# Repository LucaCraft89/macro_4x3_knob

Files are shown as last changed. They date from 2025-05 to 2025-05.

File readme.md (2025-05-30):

# macro_4x3_knob

macro_4x3_knob
Image Coming soon

* Keyboard Creators: 
- [Luca Dall'Acqua](https://github.com/lucacraft89) PCB and FW
- [Simone Folino](https://github.com/Simone02472) 3D Modeling
* Hardware Supported: Arduino Pro Micro, Custom PCB
* Hardware Availability: AliExpress or any mayor online store
* Status: New improved PCB revision and subsequent 3d Model revision in development

Make example for this keyboard (after setting up your build environment):
```bash
make macro_4x3_knob:default
```
Flashing example for this keyboard:
```bash
make macro_4x3_knob:default:flash
```
See the [build environment setup](https://docs.qmk.fm/#/getting_started_build_tools) and the [make instructions](https://docs.qmk.fm/#/getting_started_make_guide) for more information. Brand new to QMK? Start with our [Complete Newbs Guide](https://docs.qmk.fm/#/newbs).

## 3D models 
| Part  | File |
| :--- | :----: |
| TOP | [V1.0](https://github.com/LucaCraft89/macro_4x3_knob/3D/V1/top1.0.STL) | 
| BOTTOM | [V1.0](https://github.com/LucaCraft89/macro_4x3_knob/3D/V1/bottom1.0.STL) | 

## Gerber files

[V1](https://github.com/LucaCraft89/macro_4x3_knob/PCB/Gerber/V1/V1.zip)
- NOTE: PCB has space for oled display that was never implemented, ignore it

## VIAL
VIAL is supported just flash the layout
```bash
make macro_4x3_knob:vial:flash
```

## Bootloader
Enter the bootloader in 3 ways:

* **Bootmagic reset**: Hold down the key at (0,0) in the matrix (usually the top left key or Escape) and plug in the keyboard
* **Physical reset button**: Briefly press the button on the back of the PCB - some may have pads you must short instead
* **Keycode in layout**: Press the key mapped to `QK_BOOT` if it is available

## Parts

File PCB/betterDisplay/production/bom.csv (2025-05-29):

Designator | Footprint | Quantity | Value | LCSC Part #
D1, D10, D11, D12, D2, D3, D4, D5, D6, D7, D8, D9 | Diode_DO-35 | 12 | Diode
J1 | OLED_128x32 | 1 | OLED_128x32
S1, S10, S11, S12, S2, S3, S4, S5, S6, S7, S8, S9 | MX_PCB_1.00u | 12 | Keyswitch
SW1 | Encoder_EC11_MX | 1 | RotaryEncoder_Switch_MP
U1 | Arduino_Pro_Micro | 1 | Arduino_Pro_Micro

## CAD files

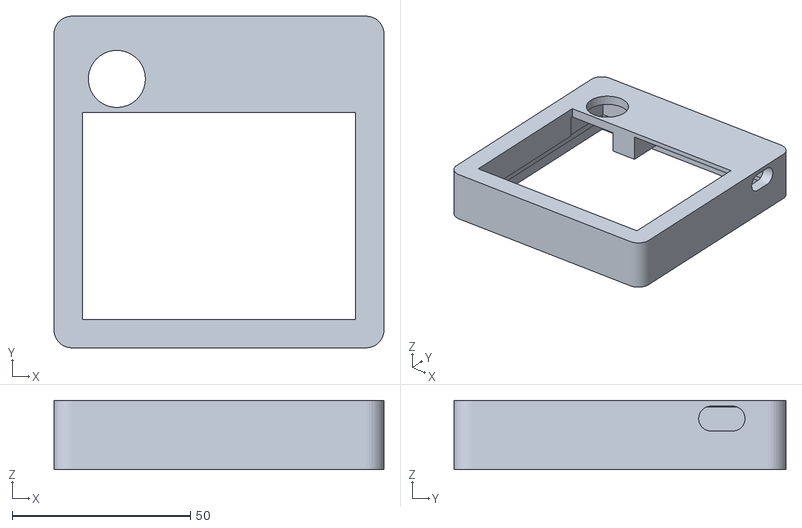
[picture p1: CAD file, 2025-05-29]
3D/V1/top1.0.STL
92.5 x 93.0 x 19.4

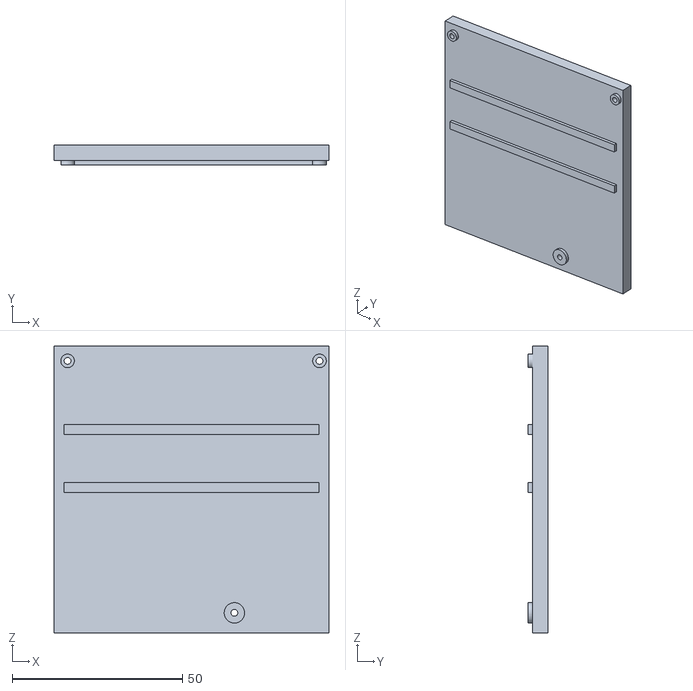
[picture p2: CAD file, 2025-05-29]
3D/V1/bottom1.0.STL
80.8 x 5.76 x 84.2

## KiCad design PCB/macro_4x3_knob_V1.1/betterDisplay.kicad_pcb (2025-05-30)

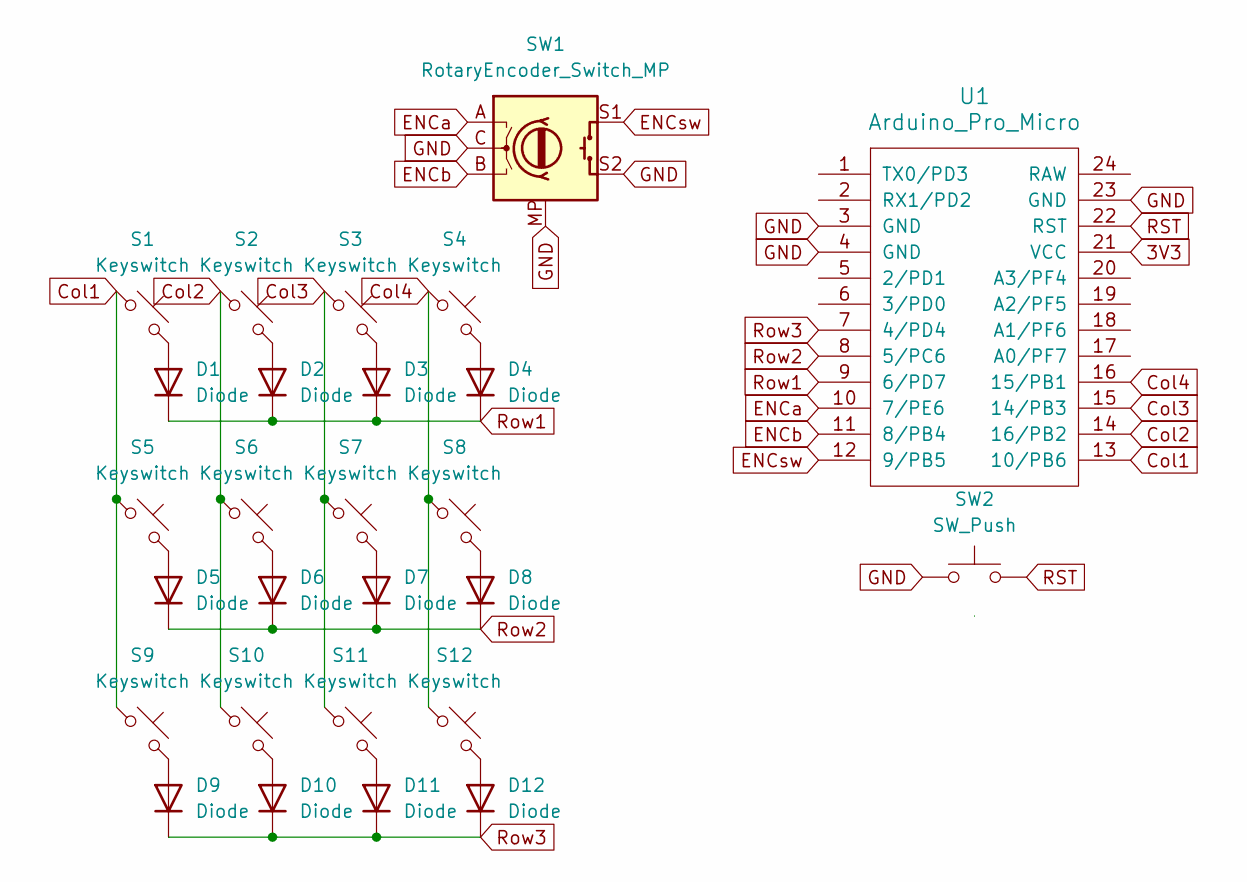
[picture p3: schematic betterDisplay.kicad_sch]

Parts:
D1, D2, D3, D4, D5, D6, D7, D8, D9, D10, D11, D12: Diode; Diode_DO-35
S1, S2, S3, S4, S5, S6, S7, S8, S9, S10, S11, S12: Keyswitch; MX_PCB_1.00u
SW1: RotaryEncoder_Switch_MP; Encoder_EC11_MX
SW2: SW_Push; SW_PUSH_6mm
U1: Arduino_Pro_Micro

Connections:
3V3: U1.21 (VCC)
Col1: S1.1, S5.1, S9.1, U1.13 (10/PB6)
Col2: S2.1, S6.1, S10.1, U1.14 (16/PB2)
Col3: S3.1, S7.1, S11.1, U1.15 (14/PB3)
Col4: S4.1, S8.1, S12.1, U1.16 (15/PB1)
ENCa: SW1.A, U1.10 (7/PE6)
ENCb: SW1.B, U1.11 (8/PB4)
ENCsw: SW1.S1, U1.12 (9/PB5)
GND: SW1.C, SW1.MP, SW1.S2, SW2.1, U1.3 (GND), U1.4 (GND), U1.23 (GND); also elsewhere on the board
unnamed: D1.2 (A), S1.2
unnamed: D2.2 (A), S2.2
unnamed: D3.2 (A), S3.2
unnamed: D4.2 (A), S4.2
unnamed: D5.2 (A), S5.2
unnamed: D6.2 (A), S6.2
unnamed: D7.2 (A), S7.2
unnamed: D8.2 (A), S8.2
unnamed: D9.2 (A), S9.2
unnamed: D10.2 (A), S10.2
unnamed: D11.2 (A), S11.2
unnamed: D12.2 (A), S12.2
RST: SW2.2, U1.22 (RST)
Row1: D1.1 (K), D2.1 (K), D3.1 (K), D4.1 (K), U1.9 (6/PD7)
Row2: D5.1 (K), D6.1 (K), D7.1 (K), D8.1 (K), U1.8 (5/PC6)
Row3: D9.1 (K), D10.1 (K), D11.1 (K), D12.1 (K), U1.7 (4/PD4)

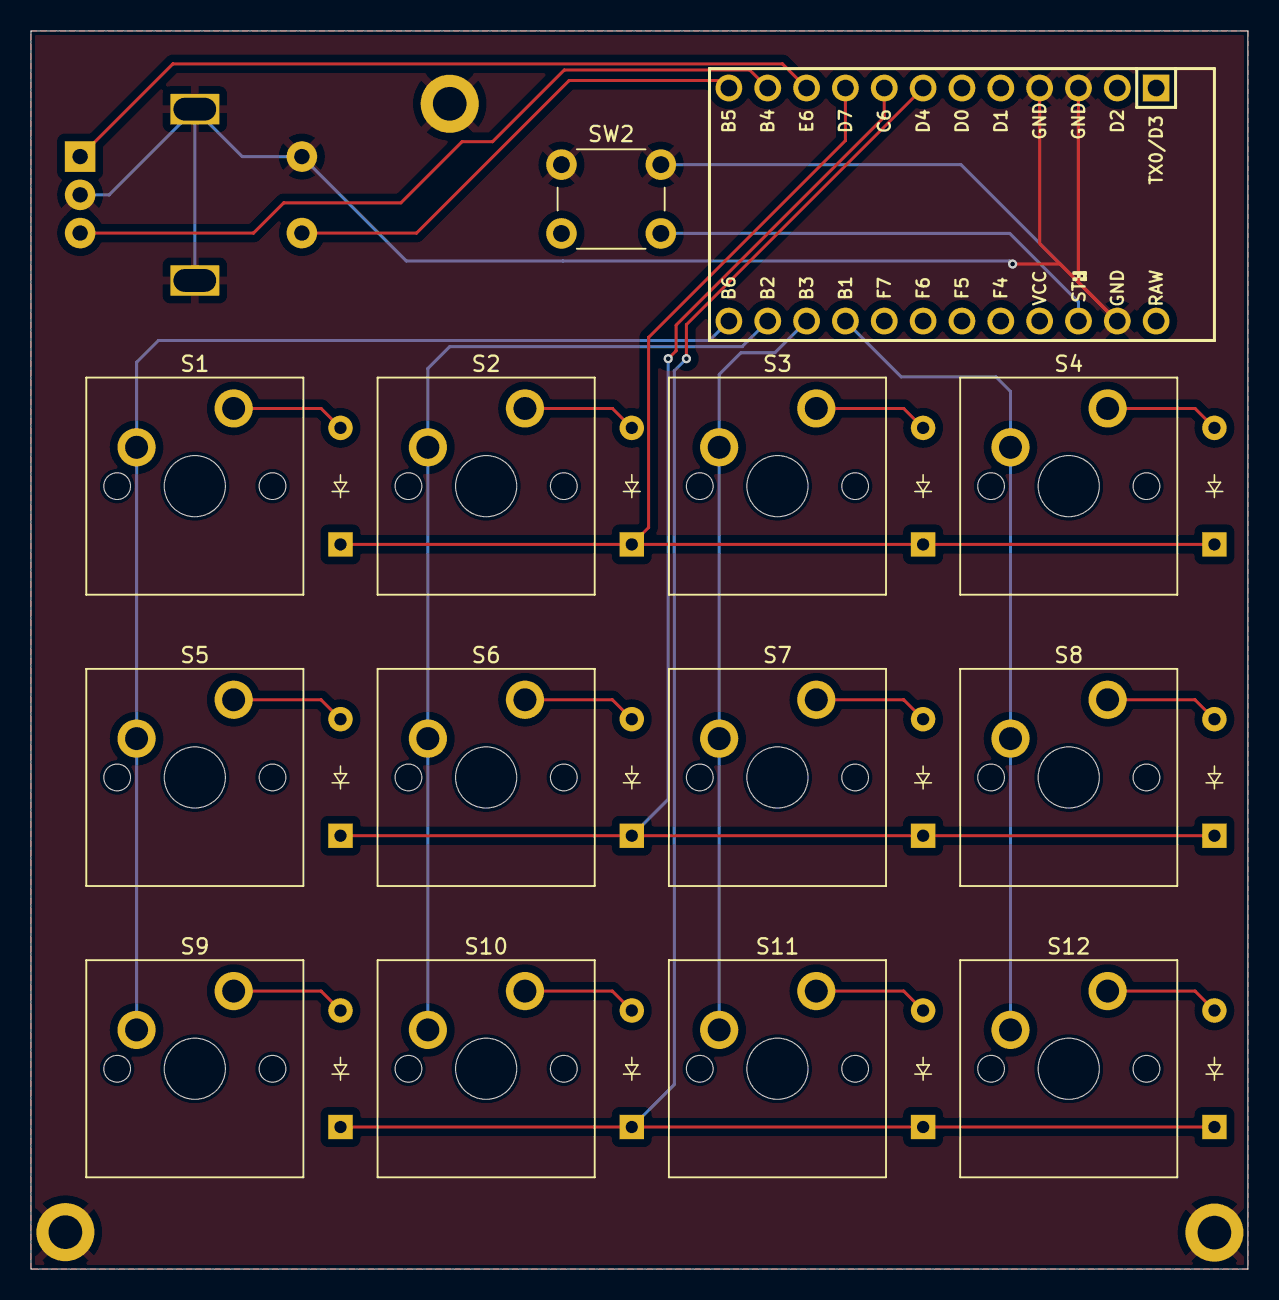
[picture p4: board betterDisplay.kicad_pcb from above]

Board: 2 copper layers, 79.6 x 81.0 mm, 28 parts (0 on the bottom side), 24 nets.

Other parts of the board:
GND: MountingHole_2.2mm_M2_ISO14580_Pad

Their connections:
GND: GND.1; also elsewhere on the board

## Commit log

2025-05-29 Add 3d
    [bottom1.0.STL, top1.0.STL]
2025-05-30 Added New PCB
    [better-B_Cu.gbl, better-B_Mask.gbs, better-B_Paste.gbp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]
